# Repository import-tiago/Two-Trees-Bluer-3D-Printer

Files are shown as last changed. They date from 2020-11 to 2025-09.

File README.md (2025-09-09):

# Two Trees BlueR - 3D Printer

Documentation, firmware and set of utilities for my own use and personal needs.

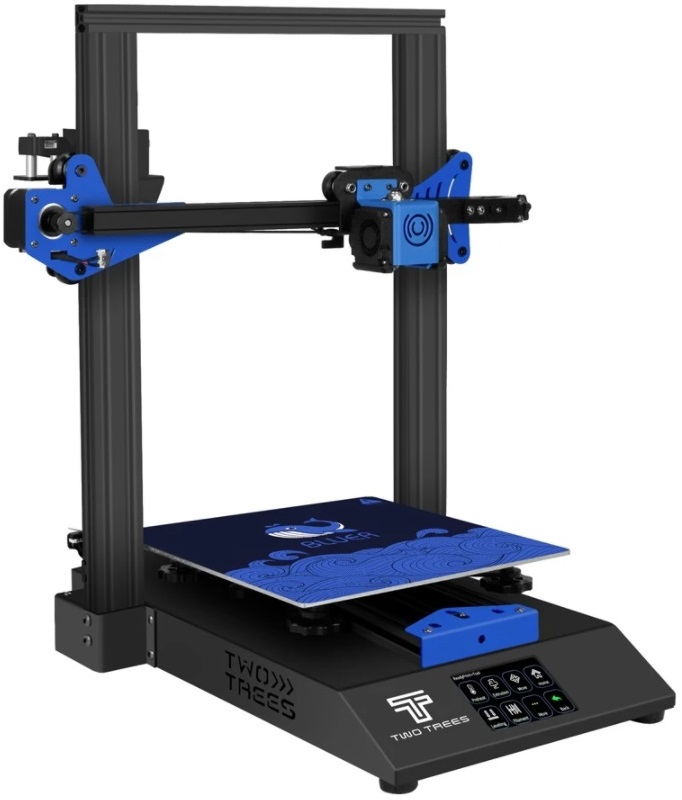
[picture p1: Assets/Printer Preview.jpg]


## Machine Specs
| Parameter | Value |
|--|--|
Number of nozzles|1|
Construction volume|235mm * 235mm * 280mm|
Printing method|SD-Card / online printing (by Serial UART communication through printer USB connector and some internet interface)|
IHM|3.5 inch color touch screen|
Machine speed|10~300mm/s|
Print speed|20~200mm/s|
Extrusion head temperature (highest)|260 °C|
Maximum hot bed temperature (highest)|100 °C|
Printing platform|Warm bed|
XY axis positioning accuracy|0.01mm|
Z axis positioning accuracy|0.004mm|
Recommended printed material|PLA, ABS and PETG|
Consumable filament diameter|1.75mm|
Print file format|G-Code|
Machine size|L=410mm * W=400mm * H=520mm|
Machine weight|7.5kg|
Power supply|127V~220V/240W|
Microcontroller|[STM32F103VET6 datasheet](Hardware/Motherboard/2.%20Datasheets/MCU/STM32F103VET6.pdf)|
Motor Driver|[TMC2209 datasheet](Hardware/Motherboard/2.%20Datasheets/Stepper%20Motor%20Driver/TMC2209.pdf)|
Stepper Motor|[US-17HS4401S datasheet](Hardware/Stepper%20Motors/US-17HS4401S.pdf)|
Motherboard|[MKS Robin Nano v1.2 schematic](Hardware/Motherboard/1.%20Schematic/MKS%20Robin%20Nano%20v1.2.pdf) ([source HW + FW](https://github.com/import-tiago-mks/MKS-Robin-Nano-V1.X))|
Display|[MKS TFT35](https://github.com/import-tiago-mks/MKS-TFT) - Parallel line communication interface (FSMC) (schematic not available)|

More information on the manufacturer's official website: https://twotrees3d.com/

# Firmware

Version|[Marlin 3D Printer Firmware](https://github.com/MarlinFirmware/Marlin/releases/tag/2.1.3-b3) (from release 2.1.3-b3) + [BlueR v3 Marlin Configurations](https://github.com/MarlinFirmware/Configurations/tree/release-2.1.3-b3/config/examples/Two%20Trees/BlueR/BlueR%20V3) (from release 2.1.3-b3) + Personal Customization|
--- | ---
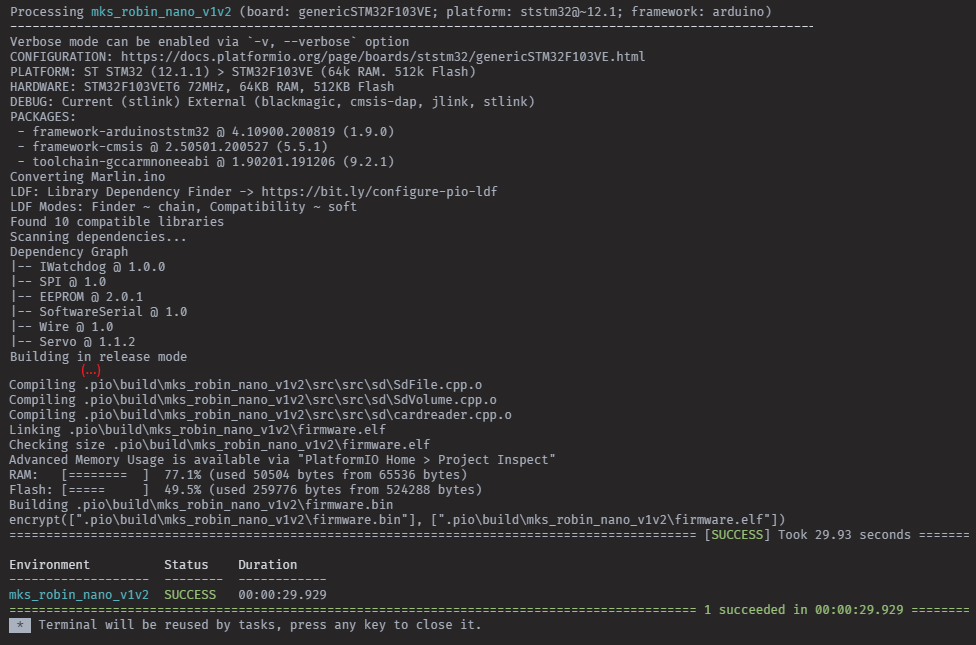
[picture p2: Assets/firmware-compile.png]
 

## Custom Modifications

**In `Configuration.h`:**
```cpp
#define BLUER_TMC2209
#define BLUER_BLTOUCH
#define Z_DRIVER_TYPE BASE_DRIVER_TYPE
#define E0_DRIVER_TYPE BASE_DRIVER_TYPE
#define Z_MIN_ENDSTOP_HIT_STATE HIGH
#define USE_PROBE_FOR_Z_HOMING
#define DEFAULT_AXIS_STEPS_PER_UNIT {160, 160, 800, 830}
#define NOZZLE_TO_PROBE_OFFSET { 0, -37, 0 }  // These values apply to *my* BLTouch mount. Adjust according to your specific bracket/mount.
//#define RESTORE_LEVELING_AFTER_G28
#define ENABLE_LEVELING_AFTER_G28
#define PREHEAT_BEFORE_LEVELING
#define ENDSTOP_NOISE_THRESHOLD 2
#define PROBING_FANS_OFF 
#define PROBING_ESTEPPERS_OFF 
#define PROBING_STEPPERS_OFF
#define DELAY_BEFORE_PROBING 200
#define MULTIPLE_PROBING 2
#define EXTRA_PROBING 1
#define GRID_MAX_POINTS_X 4
#define EXTRAPOLATE_BEYOND_GRID
#define Z_MIN_PROBE_REPEATABILITY_TEST
#define Y_MIN_POS 0
```

**In `Configuration_adv.h`:**
```cpp
#define BLTOUCH_DELAY 500
//#define BLTOUCH_FORCE_SW_MODE // must remain commented (issue #27235)
```

## Frequently Asked Questions

### What is my micro-stepping configuration?


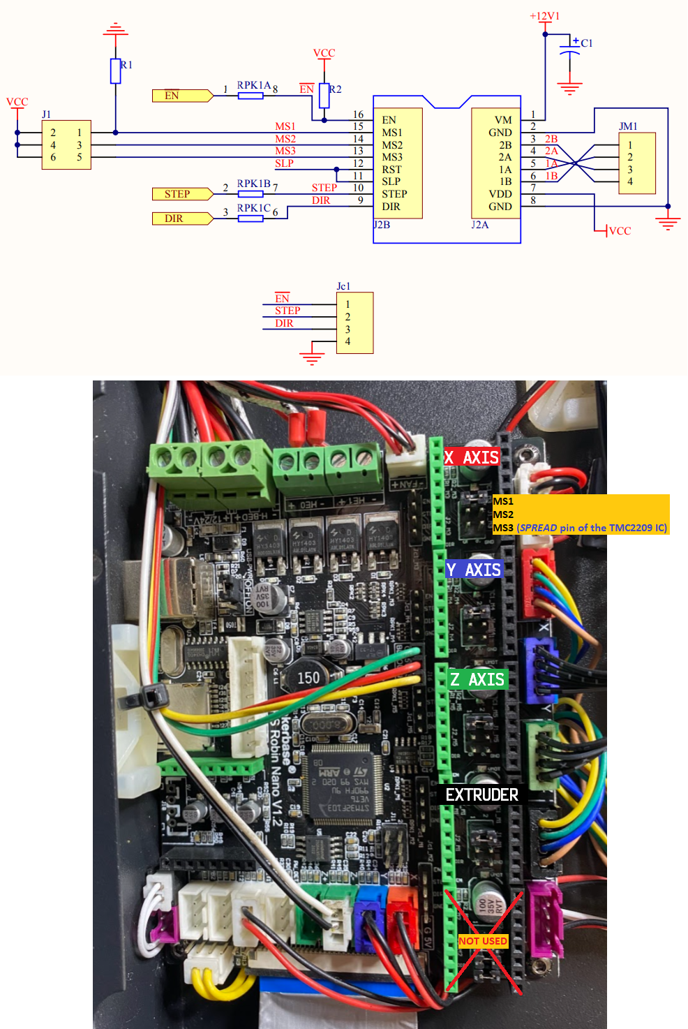
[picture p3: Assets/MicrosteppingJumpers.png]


### What VREF value I seted at motor-drivers (aka motors current definition)?

- X-axis VREF = 0.75V ∴ IRMS = 0.53A </br>
- Y-axis VREF = 0.85V ∴ IRMS = 0.60A </br>
- Z-axis VREF = 0.85V ∴ IRMS = 0.60A </br>
- E-axis VREF = 0.75V ∴ IRMS = 0.53A </br>

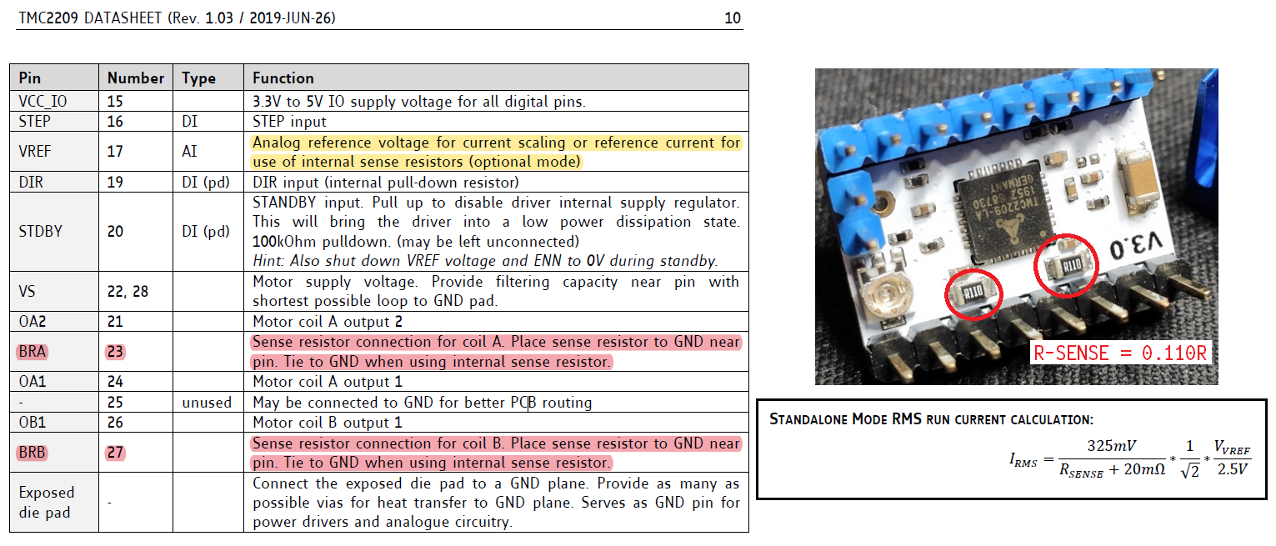
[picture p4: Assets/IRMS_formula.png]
<p align="center">    
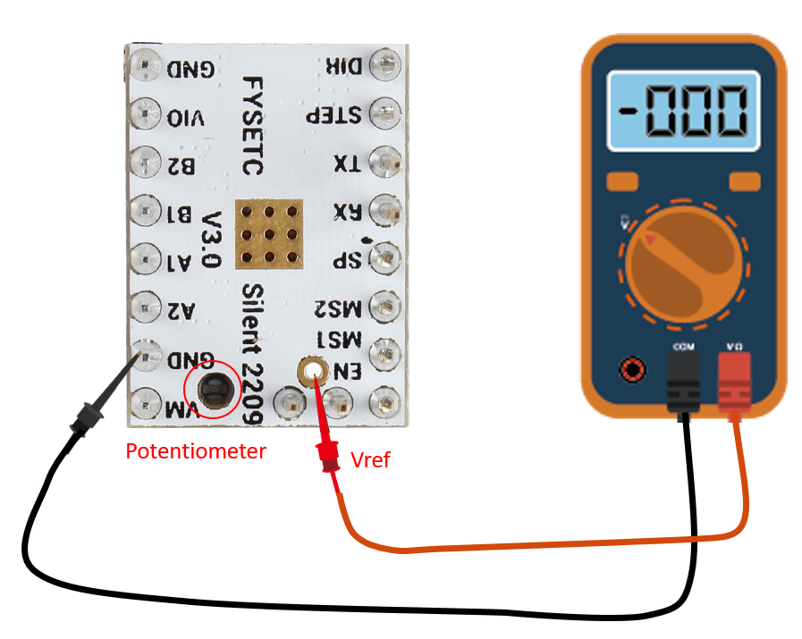
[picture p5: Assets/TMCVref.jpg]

  
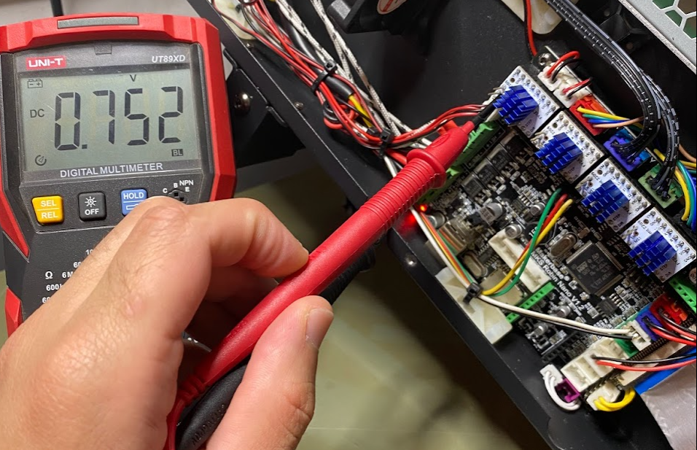
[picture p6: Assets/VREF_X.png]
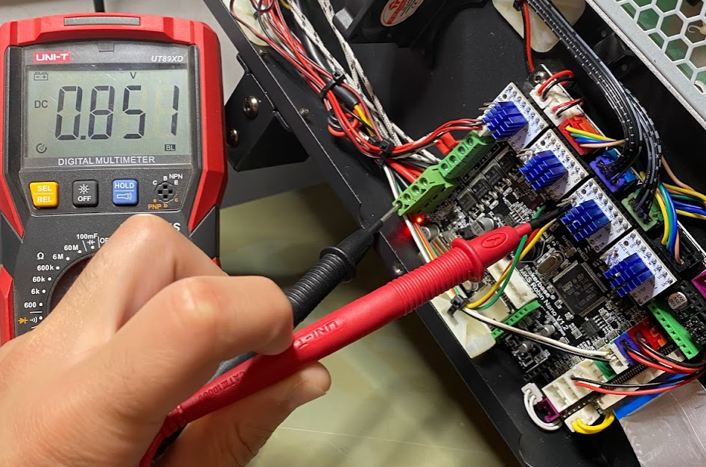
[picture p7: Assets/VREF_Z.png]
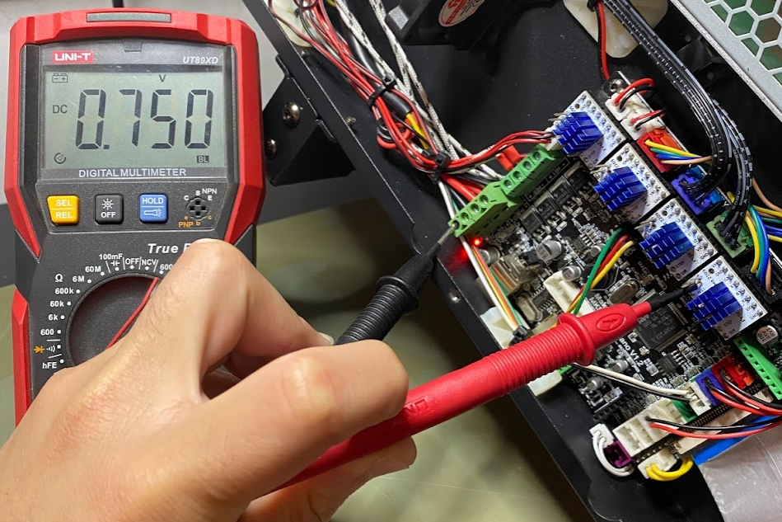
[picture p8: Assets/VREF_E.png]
|  |  |  |  |
|--|--|--|--|

## Print Samples

### Decoration Models
#### Among Us ([STL](https://www.thingiverse.com/thing:4626168))

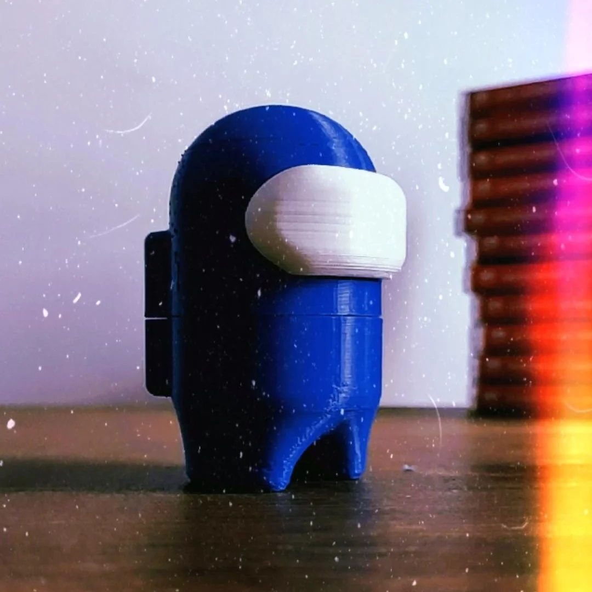
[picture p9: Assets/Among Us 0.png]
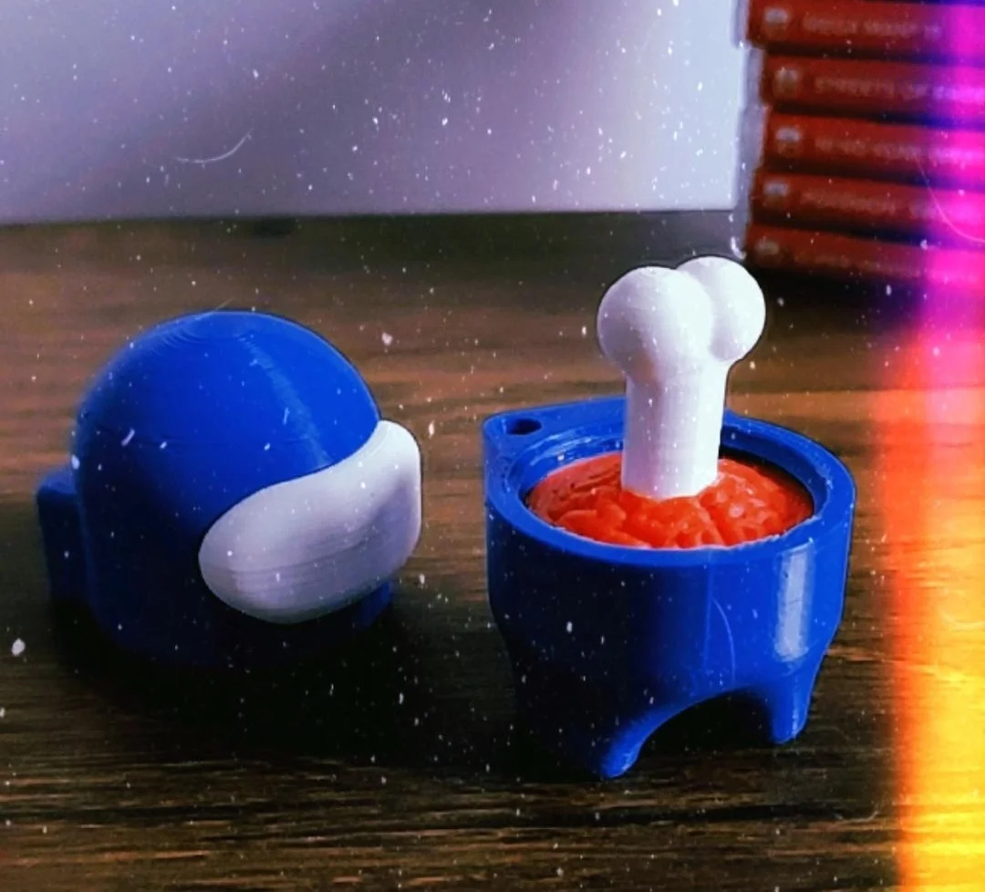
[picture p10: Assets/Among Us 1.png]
 | 
--- | ---

#### Bulbasaur Planter ([STL](https://www.thingiverse.com/thing:633081))


### Tools & Utensils
#### SD & Micro SD Card Box ([STL](https://www.thingiverse.com/thing:3611322))


#### 18650 Battery Box (x8) ([STL](https://www.thingiverse.com/thing:3191180))


#### Dust Filament Filter ([STL](https://www.thingiverse.com/thing:1692395))
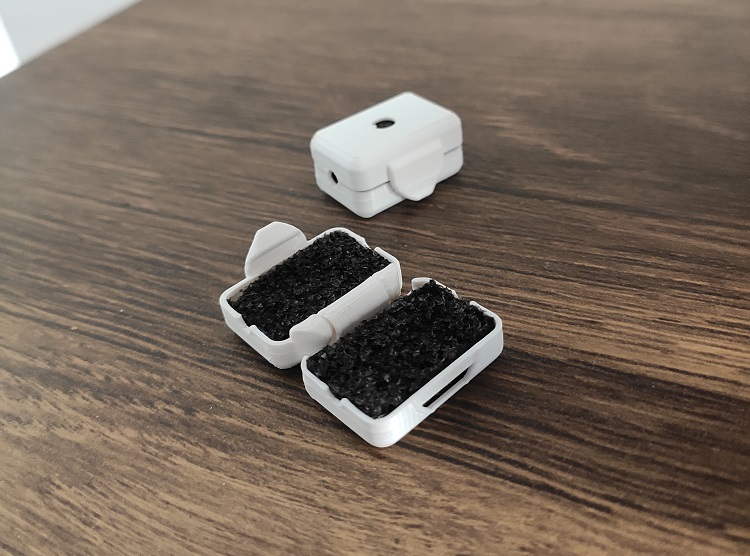
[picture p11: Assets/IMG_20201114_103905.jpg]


#### Universal Filament Clip ([STL](https://www.thingiverse.com/thing:3757356))


### Calibration & Tests
#### XYZ Cube ([STL](https://www.thingiverse.com/thing:1278865))
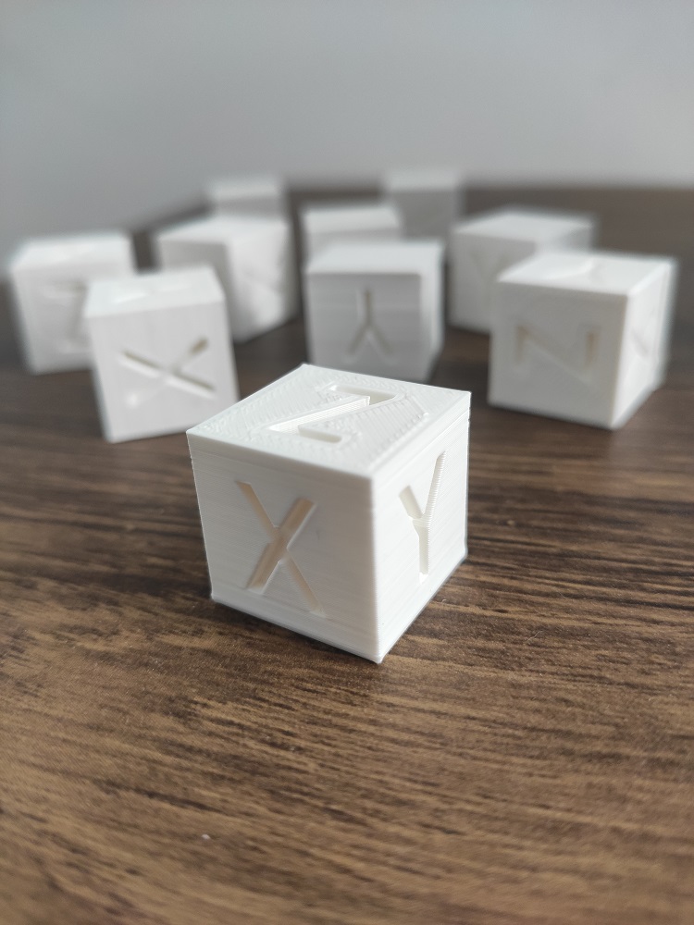
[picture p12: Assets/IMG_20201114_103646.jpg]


### BlueR Self-Upgrades Parts
#### BLTtouch Support (front mounting) ([STL](https://moltech3d.com/blog/2020/10/05/suporte-para-fixacao-do-bltouch-na-impressora-twotrees-bluer/))


## Improved Components and Upgrades
- [x] Stepper motor driver - [TMC2209](https://pt.aliexpress.com/item/1005004894012542.html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) at X, Y, Z and E - **ultra-silent controllers**
- [x] Auto leveling sensor - [3D Touch](https://pt.aliexpress.com/item/1005004256711867.html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) - **Automatic and improved bed leveling**
- [x] PEI spring steel sheet with magnetic base [235mm x 235mm](https://www.aliexpress.com/item/1005004111663711.html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) - **better adhesion and increase surface hardness**
- [x] Anti-backlash spring loaded nut - [T8](https://pt.aliexpress.com/item/32820989850.html?spm=a2g0o.cart.0.0.4d623c00aKJcGs&mp=1) - **Smooths lines on the z axis**

## Printer Details
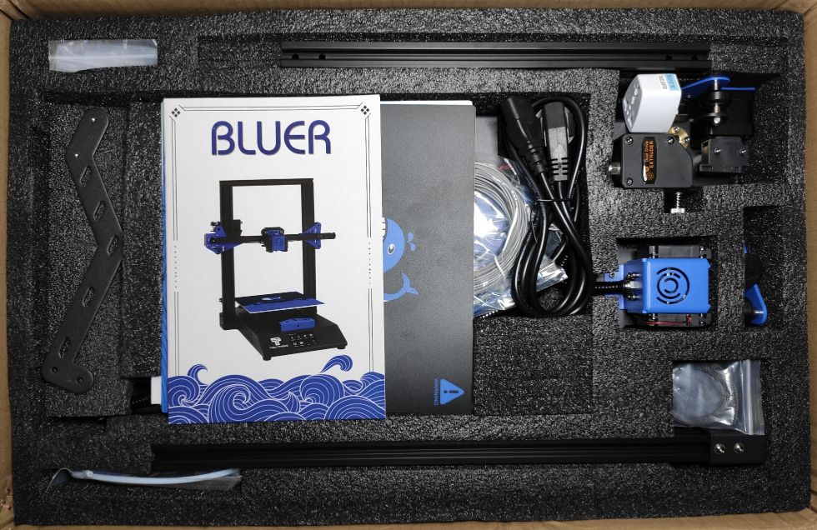
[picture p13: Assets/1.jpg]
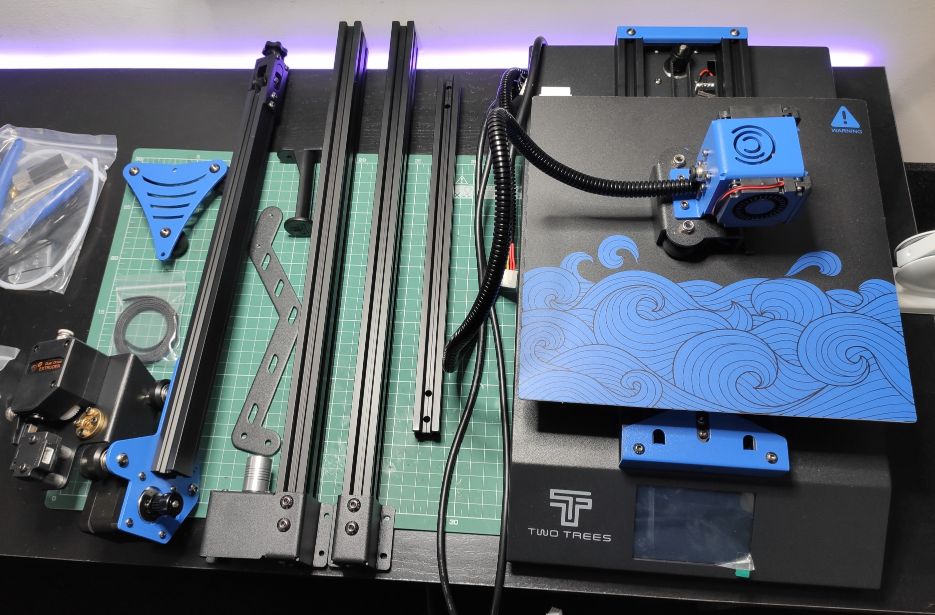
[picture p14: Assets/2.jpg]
|  |  |  |
|--|--|--|
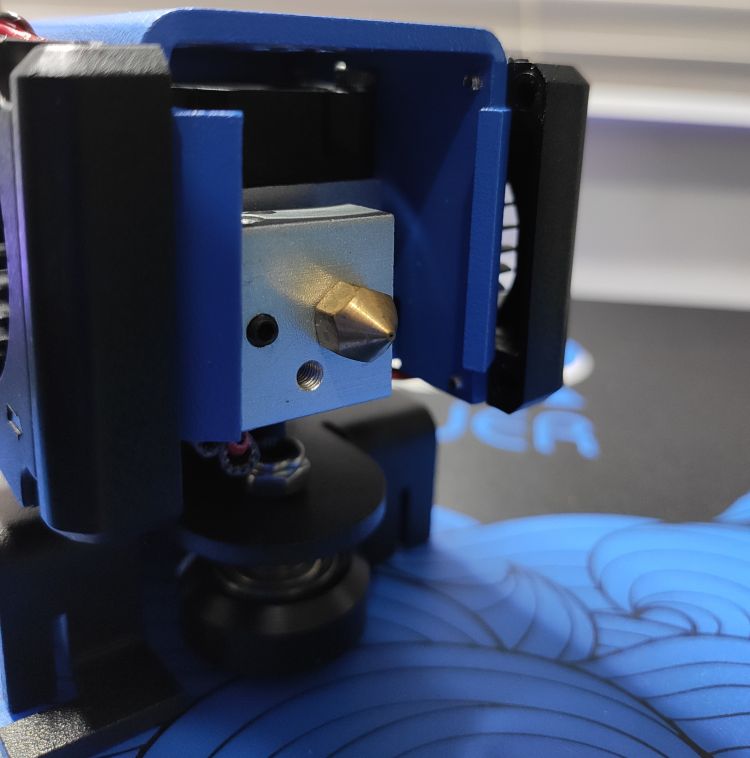
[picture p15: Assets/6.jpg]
|  |  |  |
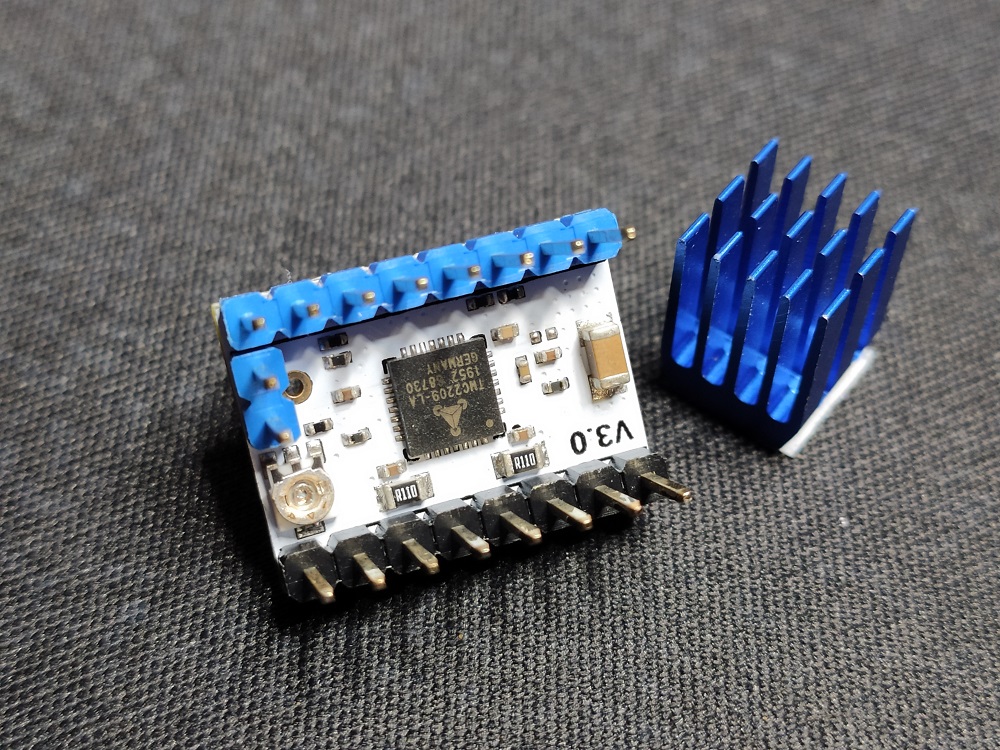
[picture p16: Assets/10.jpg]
|  |  |  |

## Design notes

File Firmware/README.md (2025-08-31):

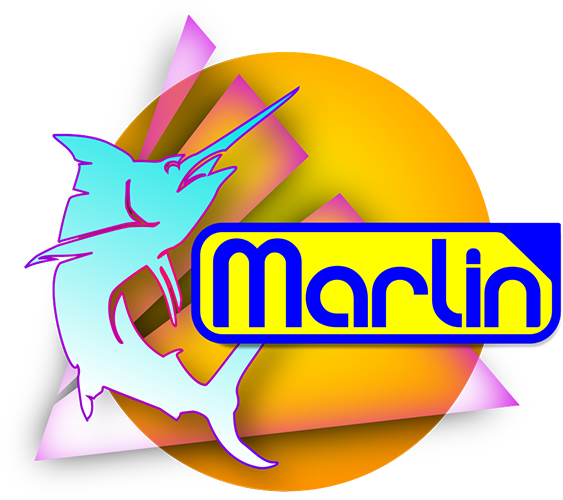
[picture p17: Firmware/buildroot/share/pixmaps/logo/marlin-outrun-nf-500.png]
MarlinFirmware's logo


<h1 align="center">Marlin 3D Printer Firmware</h1>

<p align="center">
    
    
    
    
    
    <br />
    
    
</p>

### 🌍 Translations
<table>
<tr>
  <td><a href="//translate.google.com/translate?u=github.com/MarlinFirmware/Marlin&sl=auto&tl=an">Aragonés</a></td>
  <td><a href="//translate.google.com/translate?u=github.com/MarlinFirmware/Marlin&sl=auto&tl=bg">Български</a></td>
  <td><a href="//translate.google.com/translate?u=github.com/MarlinFirmware/Marlin&sl=auto&tl=ca">Català</a></td>
  <td><a href="//translate.google.com/translate?u=github.com/MarlinFirmware/Marlin&sl=auto&tl=cs">Čeština</a></td>
  <td><a href="//translate.google.com/translate?u=github.com/MarlinFirmware/Marlin&sl=auto&tl=da">Dansk</a></td>
  <td><a href="//translate.google.com/translate?u=github.com/MarlinFirmware/Marlin&sl=auto&tl=de">Deutsch</a></td>
  <td><a href="//translate.google.com/translate?u=github.com/MarlinFirmware/Marlin&sl=auto&tl=el">Ελληνικά</a></td>
</tr>
<tr>
  <td><a href="//github.com/MarlinFirmware/Marlin">English</a></td>
  <td><a href="//translate.google.com/translate?u=github.com/MarlinFirmware/Marlin&sl=auto&tl=es">Español</a></td>
  <td><a href="//translate.google.com/translate?u=github.com/MarlinFirmware/Marlin&sl=auto&tl=eu">Euskara</a></td>
  <td><a href="//translate.google.com/translate?u=github.com/MarlinFirmware/Marlin&sl=auto&tl=fi">Suomi</a></td>
  <td><a href="//translate.google.com/translate?u=github.com/MarlinFirmware/Marlin&sl=auto&tl=fr">Français</a></td>
  <td><a href="//translate.google.com/translate?u=github.com/MarlinFirmware/Marlin&sl=auto&tl=gl">Galego</a></td>
  <td><a href="//translate.google.com/translate?u=github.com/MarlinFirmware/Marlin&sl=auto&tl=hr">Hrvatski</a></td>
</tr>
<tr>
  <td><a href="//translate.google.com/translate?u=github.com/MarlinFirmware/Marlin&sl=auto&tl=hu">Magyar</a></td>
  <td><a href="//translate.google.com/translate?u=github.com/MarlinFirmware/Marlin&sl=auto&tl=it">Italiano</a></td>
  <td><a href="//translate.google.com/translate?u=github.com/MarlinFirmware/Marlin&sl=auto&tl=ja">にほんご</a></td>
  <td><a href="//translate.google.com/translate?u=github.com/MarlinFirmware/Marlin&sl=auto&tl=ko">한국어</a></td>
  <td><a href="//translate.google.com/translate?u=github.com/MarlinFirmware/Marlin&sl=auto&tl=nl">Nederlands</a></td>
  <td><a href="//translate.google.com/translate?u=github.com/MarlinFirmware/Marlin&sl=auto&tl=pl">Polski</a></td>
  <td><a href="//translate.google.com/translate?u=github.com/MarlinFirmware/Marlin&sl=auto&tl=pt">Português</a></td>
</tr>
<tr>
  <td><a href="//translate.google.com/translate?u=github.com/MarlinFirmware/Marlin&sl=auto&tl=pt-BR">Português (Brasil)</a></td>
  <td><a href="//translate.google.com/translate?u=github.com/MarlinFirmware/Marlin&sl=auto&tl=ro">Română</a></td>
  <td><a href="//translate.google.com/translate?u=github.com/MarlinFirmware/Marlin&sl=auto&tl=ru">Русский</a></td>
  <td><a href="//translate.google.com/translate?u=github.com/MarlinFirmware/Marlin&sl=auto&tl=sk">Slovenčina</a></td>
  <td><a href="//translate.google.com/translate?u=github.com/MarlinFirmware/Marlin&sl=auto&tl=sv">Svenska</a></td>
  <td><a href="//translate.google.com/translate?u=github.com/MarlinFirmware/Marlin&sl=auto&tl=tr">Türkçe</a></td>
  <td><a href="//translate.google.com/translate?u=github.com/MarlinFirmware/Marlin&sl=auto&tl=uk">Українська</a></td>
</tr>
<tr>
  <td><a href="//translate.google.com/translate?u=github.com/MarlinFirmware/Marlin&sl=auto&tl=vi">Tiếng Việt</a></td>
  <td><a href="//translate.google.com/translate?u=github.com/MarlinFirmware/Marlin&sl=auto&tl=zh-CN">简体中文</a></td>
  <td><a href="//translate.google.com/translate?u=github.com/MarlinFirmware/Marlin&sl=auto&tl=zh-TW">繁體中文</a></td>
  <td></td>
  <td></td>
  <td></td>
  <td></td>
</tr>
</table>

Additional documentation can be found at the [Marlin Home Page](//marlinfw.org/).
Please test this firmware and let us know if it misbehaves in any way. Volunteers are standing by!

---

## Marlin 2.1.3 Beta 3

__Not for production use. Use with caution!__

This branch is for testing and bug fixes for Marlin 2.1.3. We'll use this time to collect bug reports and patch as many issues as we can. This should help the release version of 2.1.3 to be as robust as we can make it. Are you ready to do some testing?

## Configuration Migration

There are a lot of configuration changes in Marlin 2.1.3. We're working on automated tools to migrate configurations, so if you want to help us test those get in touch on the [Marlin Discord](//discord.com/servers/marlin-firmware-461605380783472640). If you need help migrating your configurations to Marlin 2.1.3, we'll have a dedicated channel for this purpose. Post your configurations there and we'll send back updated configurations. We can also send a built `firmware.bin` file if you need it.

## Example Configurations

Before you can build Marlin for your machine you'll need a configuration for your specific hardware. Upon request, your vendor will be happy to provide you with the complete source code and configurations for your machine, but you'll need to get updated configuration files if you want to install a newer version of Marlin. Fortunately, Marlin users have contributed dozens of tested configurations to get you started. Visit the [MarlinFirmware/Configurations](//github.com/MarlinFirmware/Configurations) repository to find the right configuration for your hardware.

## Marlin Builds

We now publish builds for all our posted example configurations. See the [MarlinBuilds](//github.com/MarlinFirmware/MarlinBuilds) repository for details. This is a new process so bear with us while we work out all the best variants. If you like the way an example configuration works but think it could be better, please submit your suggested improvements in a **Pull Request**.

## Building Marlin 2.1

To build and upload Marlin you will use one of these tools:

- The free [Visual Studio Code](//code.visualstudio.com/download) using the [Auto Build Marlin](//marlinfw.org/docs/basics/auto_build_marlin.html) extension.
- The free [Arduino IDE](//www.arduino.cc/en/main/software) : See [Building Marlin with Arduino](//marlinfw.org/docs/basics/install_arduino.html)
- You can also use VSCode with devcontainer : See [Installing Marlin (VSCode devcontainer)](http://marlinfw.org/docs/basics/install_devcontainer_vscode.html).

Marlin is optimized to build with the **PlatformIO IDE** extension for **Visual Studio Code**. You can still build Marlin with **Arduino IDE**, and we hope to improve the Arduino build experience, but at this time PlatformIO is the better choice.

## 8-Bit AVR Boards

We intend to continue supporting 8-bit AVR boards in perpetuity, maintaining a single codebase that can apply to all machines. We want casual hobbyists and tinkerers and owners of older machines to benefit from the community's innovations just as much as those with fancier machines. Plus, those old AVR-based machines are often the best for your testing and feedback!

## Hardware Abstraction Layer (HAL)

Marlin includes an abstraction layer to provide a common API for all the platforms it targets. This allows Marlin code to address the details of motion and user interface tasks at the lowest and highest levels with no system overhead, tying all events directly to the hardware clock.

Every new HAL opens up a world of hardware. At this time we need HALs for RP2040 and the Duet3D family of boards. A HAL that wraps an RTOS is an interesting concept that could be explored. Did you know that Marlin includes a Simulator that can run on Windows, macOS, and Linux? Join the Discord to help move these sub-projects forward!

### Supported Platforms

  Platform|MCU|Example Boards
  --------|---|-------
  [Arduino AVR](//www.arduino.cc/)|ATmega|RAMPS, Melzi, RAMBo
  [Teensy++ 2.0](//www.microchip.com/en-us/product/AT90USB1286)|AT90USB1286|Printrboard
  [Arduino Due](//www.arduino.cc/en/Guide/ArduinoDue)|SAM3X8E|RAMPS-FD, RADDS, RAMPS4DUE
  [ESP32](//github.com/espressif/arduino-esp32)|ESP32|FYSETC E4, E4d@BOX, MRR
  [GD32](//www.gigadevice.com/)|GD32 ARM Cortex-M4|Creality MFL GD32 V4.2.2
  [HC32](//www.huazhoucn.com/)|HC32|Ender-2 Pro, Voxelab Aquila
  [LPC1768](//www.nxp.com/products/processors-and-microcontrollers/arm-microcontrollers/general-purpose-mcus/lpc1700-cortex-m3/512-kb-flash-64-kb-sram-ethernet-usb-lqfp100-package:LPC1768FBD100)|ARM® Cortex-M3|MKS SBASE, Re-ARM, Selena Compact
  [LPC1769](//www.nxp.com/products/processors-and-microcontrollers/arm-microcontrollers/general-purpose-mcus/lpc1700-cortex-m3/512-kb-flash-64-kb-sram-ethernet-usb-lqfp100-package:LPC1769FBD100)|ARM® Cortex-M3|Smoothieboard, Azteeg X5 mini, TH3D EZBoard
  [Pico RP2040](//www.raspberrypi.com/documentation/microcontrollers/pico-series.html)|Dual Cortex M0+|BigTreeTech SKR Pico
  [STM32F103](//www.st.com/en/microcontrollers-microprocessors/stm32f103.html)|ARM® Cortex-M3|Malyan M200, GTM32 Pro, MKS Robin, BTT SKR Mini
  [STM32F401](//www.st.com/en/microcontrollers-microprocessors/stm32f401.html)|ARM® Cortex-M4|ARMED, Rumba32, SKR Pro, Lerdge, FYSETC S6, Artillery Ruby
  [STM32F7x6](//www.st.com/en/microcontrollers-microprocessors/stm32f7x6.html)|ARM® Cortex-M7|The Borg, RemRam V1
  [STM32G0B1RET6](//www.st.com/en/microcontrollers-microprocessors/stm32g0x1.html)|ARM® Cortex-M0+|BigTreeTech SKR mini E3 V3.0
  [STM32H743xIT6](//www.st.com/en/microcontrollers-microprocessors/stm32h743-753.html)|ARM® Cortex-M7|BigTreeTech SKR V3.0, SKR EZ V3.0, SKR SE BX V2.0/V3.0
  [SAMD21P20A](//www.adafruit.com/product/4064)|ARM® Cortex-M0+|Adafruit Grand Central M4
  [SAMD51P20A](//www.adafruit.com/product/4064)|ARM® Cortex-M4|Adafruit Grand Central M4
  [Teensy 3.2/3.1](//www.pjrc.com/teensy/teensy31.html)|MK20DX256VLH7 ARM® Cortex-M4|
  [Teensy 3.5](//www.pjrc.com/store/teensy35.html)|MK64FX512-VMD12 ARM® Cortex-M4|
  [Teensy 3.6](//www.pjrc.com/store/teensy36.html)|MK66FX1MB-VMD18 ARM® Cortex-M4|
  [Teensy 4.0](//www.pjrc.com/store/teensy40.html)|MIMXRT1062-DVL6B ARM® Cortex-M7|
  [Teensy 4.1](//www.pjrc.com/store/teensy41.html)|MIMXRT1062-DVJ6B ARM® Cortex-M7|
  Linux Native|x86 / ARM / RISC-V|Raspberry Pi GPIO
  Simulator|Windows, macOS, Linux|Desktop OS
  [All supported boards](//marlinfw.org/docs/hardware/boards.html#boards-list)|All platforms|All boards

## Marlin Support

The Issue Queue is reserved for Bug Reports and Feature Requests. Please use the following resources for help with configuration and troubleshooting:

- [Marlin Documentation](//marlinfw.org) - Official Marlin documentation
- [Marlin Discord](//discord.com/servers/marlin-firmware-461605380783472640) - Discuss issues with Marlin users and developers
- Facebook Group ["Marlin Firmware"](//www.facebook.com/groups/1049718498464482/)
- RepRap.org [Marlin Forum](//forums.reprap.org/list.php?415)
- Facebook Group ["Marlin Firmware for 3D Printers"](//www.facebook.com/groups/3Dtechtalk/)
- [Marlin Configuration](//www.youtube.com/results?search_query=marlin+configuration) on YouTube

## Contributing Patches

You can contribute patches by submitting a Pull Request to the ([bugfix-2.1.x](//github.com/MarlinFirmware/Marlin/tree/bugfix-2.1.x)) branch.

- We use branches named with a "bugfix" or "dev" prefix to fix bugs and integrate new features.
- Follow the [Coding Standards](//marlinfw.org/docs/development/coding_standards.html) to gain points with the maintainers.
- Please submit Feature Requests and Bug Reports to the [Issue Queue](//github.com/MarlinFirmware/Marlin/issues/new/choose). See above for user support.
- Whenever you add new features, be sure to add one or more build tests to `buildroot/tests`. Any tests added to a PR will be run within that PR on GitHub servers as soon as they are pushed. To minimize iteration be sure to run your new tests locally, if possible.
  - Local build tests:
    - All: `make tests-config-all-local`
    - Single: `make tests-config-single-local TEST_TARGET=...`
  - Local build tests in Docker:
    - All: `make tests-config-all-local-docker`
    - Single: `make tests-config-all-local-docker TEST_TARGET=...`
  - To run all unit test suites:
    - Using PIO: `platformio run -t test-marlin`
    - Using Make: `make unit-test-all-local`
    - Using Docker + make: `maker unit-test-all-local-docker`
  - To run a single unit test suite:
    - Using PIO: `platformio run -t marlin_<test-suite-name>`
    - Using make: `make unit-test-single-local TEST_TARGET=<test-suite-name>`
    - Using Docker + make: `maker unit-test-single-local-docker TEST_TARGET=<test-suite-name>`
- If your feature can be unit tested, add one or more unit tests. For more information see our documentation on [Unit Tests](test).

## Contributors

Marlin is constantly improving thanks to a huge number of contributors from all over the world bringing their specialties and talents. Huge thanks are due to [all the contributors](//github.com/MarlinFirmware/Marlin/graphs/contributors) who regularly patch up bugs, help direct traffic, and basically keep Marlin from falling apart. Marlin's continued existence would not be possible without them.

Marlin Firmware original logo design by Ahmet Cem TURAN [@ahmetcemturan](//github.com/ahmetcemturan).

## Project Leadership

Name|Role|Link|Donate
----|----|----|----
🇺🇸 Scott Lahteine|Project Lead|[[@thinkyhead](//github.com/thinkyhead)]|[💸 Donate](//marlinfw.org/docs/development/contributing.html#donate)
🇺🇸 Roxanne Neufeld|Admin|[[@Roxy-3D](//github.com/Roxy-3D)]|
🇺🇸 Keith Bennett|Admin|[[@thisiskeithb](//github.com/thisiskeithb)]|[💸 Donate](//github.com/sponsors/thisiskeithb)
🇺🇸 Jason Smith|Admin|[[@sjasonsmith](//github.com/sjasonsmith)]|
🇧🇷 Victor Oliveira|Admin|[[@rhapsodyv](//github.com/rhapsodyv)]|
🇬🇧 Chris Pepper|Admin|[[@p3p](//github.com/p3p)]|
🇳🇿 Peter Ellens|Admin|[[@ellensp](//github.com/ellensp)]|[💸 Donate](//ko-fi.com/ellensp)
🇺🇸 Bob Kuhn|Admin|[[@Bob-the-Kuhn](//github.com/Bob-the-Kuhn)]|
🇳🇱 Erik van der Zalm|Founder|[[@ErikZalm](//github.com/ErikZalm)]|

## Star History

<a id="starchart" href="//star-history.com/#MarlinFirmware/Marlin&Date">
  <picture>
    <source media="(prefers-color-scheme: dark)" srcset="https://api.star-history.com/svg?repos=MarlinFirmware/Marlin&type=Date&theme=dark" />
    <source media="(prefers-color-scheme: light)" srcset="https://api.star-history.com/svg?repos=MarlinFirmware/Marlin&type=Date" />
    Star History Chart
  </picture>
</a>

## License

Marlin is published under the [GPL license](/LICENSE) because we believe in open development. The GPL comes with both rights and obligations. Whether you use Marlin firmware as the driver for your open or closed-source product, you must keep Marlin open, and you must provide your compatible Marlin source code to end users upon request. The most straightforward way to comply with the Marlin license is to make a fork of Marlin on Github, perform your modifications, and direct users to your modified fork.

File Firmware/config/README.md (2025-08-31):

# Where have all the configurations gone?

Marlin configurations for specific machines are now maintained in their own repository at:

## https://github.com/MarlinFirmware/Configurations/tree/2.1.3-b3

Configuration files for use with the nightly `bugfix-2.1.x` branch can be downloaded from:

## https://github.com/MarlinFirmware/Configurations/archive/bugfix-2.1.x.zip

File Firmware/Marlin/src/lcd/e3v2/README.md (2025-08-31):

# DWIN for Creality Ender-3 v2

Marlin's Ender-3 v2 support requires the `DWIN_SET` included with the Ender-3 V2 [example configuration](https://github.com/MarlinFirmware/Configurations/tree/2.1.3-b3/config/examples/Creality/Ender-3%20V2).

## Easy Install

Copy the `DWIN_SET` folder onto a Micro-SD card and insert the card into the slot on the DWIN screen. Cycle the machine and wait for the screen to go from blue to orange. Turn the machine off and remove the SD card. When you turn on the machine the screen will display a "Creality" loading screen.

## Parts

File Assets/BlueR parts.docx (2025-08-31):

GENERIC HOTEND OVERVIEW

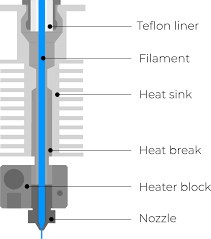
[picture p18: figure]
Anatomy of BCN 3D Sigma & Sigmax R19 extrusion system

NOZZLE TYPES

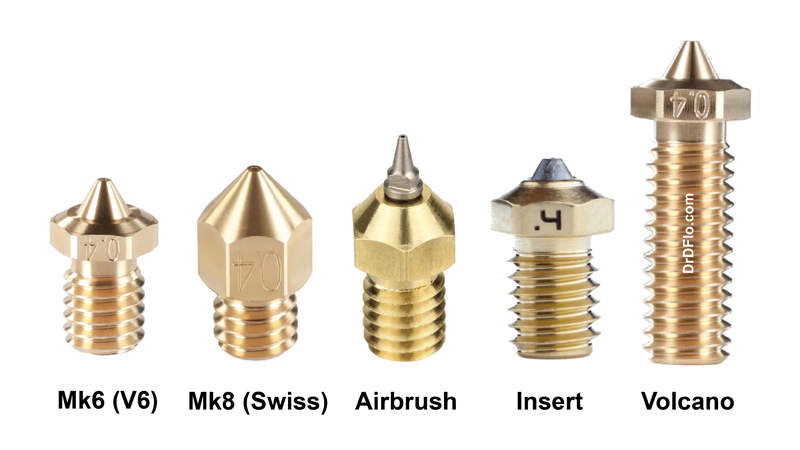
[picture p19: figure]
How to choose best nozzle for 3d printing?

HEATER BLOCK TYPES

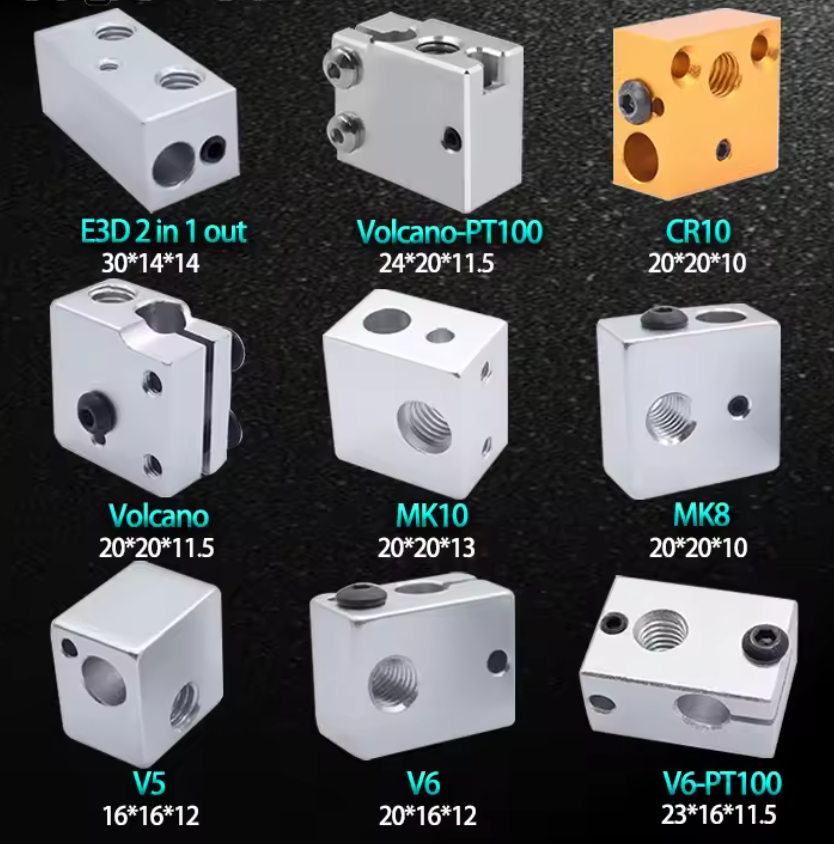
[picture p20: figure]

HEAT BREAK TYPES

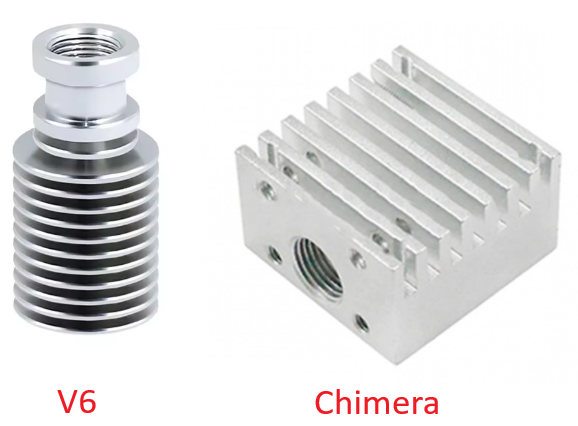
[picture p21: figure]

BLUER ORIGINAL PATS

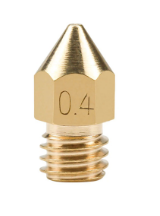
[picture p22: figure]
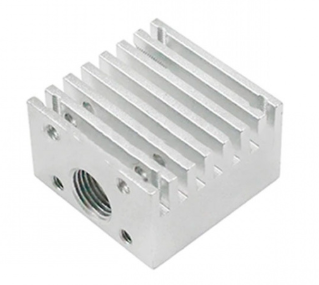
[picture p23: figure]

Nozzle: MK8 | Heat sink: Chimera (same as “Kraken” and “Cyclops”)

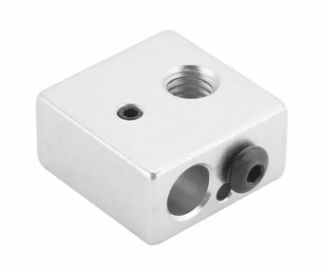
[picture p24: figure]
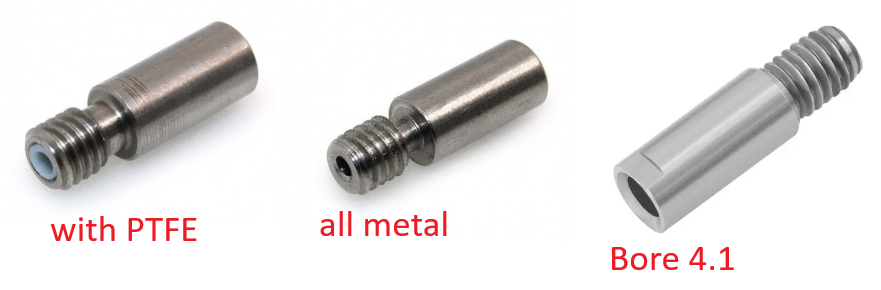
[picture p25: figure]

Heater block: MK8 | Heat Break: Chimera (same as “Kraken”)

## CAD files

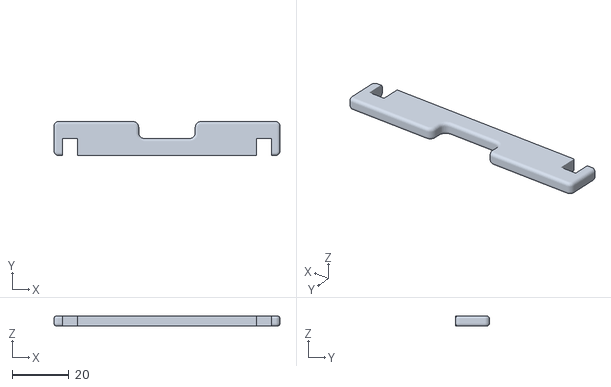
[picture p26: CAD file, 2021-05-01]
3D Models/Dupontt Jumper Wires Organizer/Short Spacers (10cm Jumpers).stl
80.0 x 12.0 x 3.70

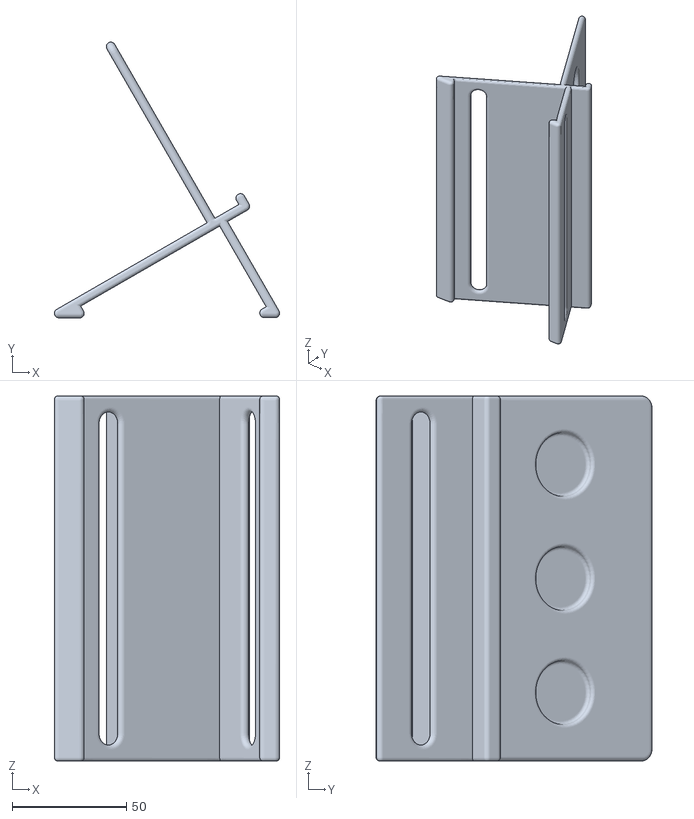
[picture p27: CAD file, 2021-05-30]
3D Models/Phone + Power Bank Table Stand/Table Phone Holder (Horizontal).stl
98.7 x 120.9 x 160.0

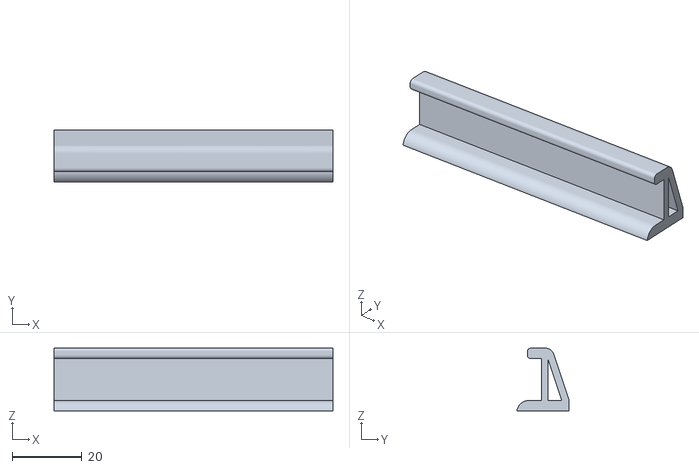
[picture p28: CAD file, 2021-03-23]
3D Models/Phone Wall Holder/Phone Wall Holder.stl
80.0 x 15.0 x 18.0

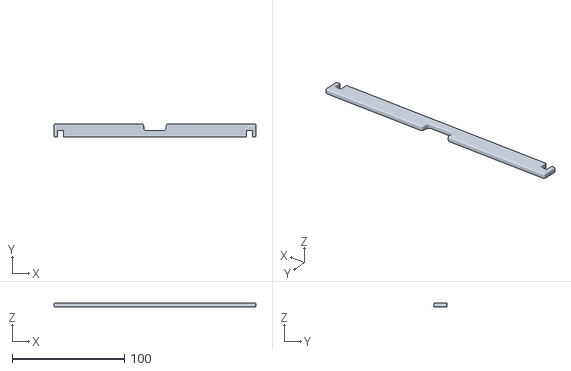
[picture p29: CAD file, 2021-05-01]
3D Models/Dupontt Jumper Wires Organizer/Long Spacers (20cm Jumpers).stl
180.0 x 12.0 x 3.70

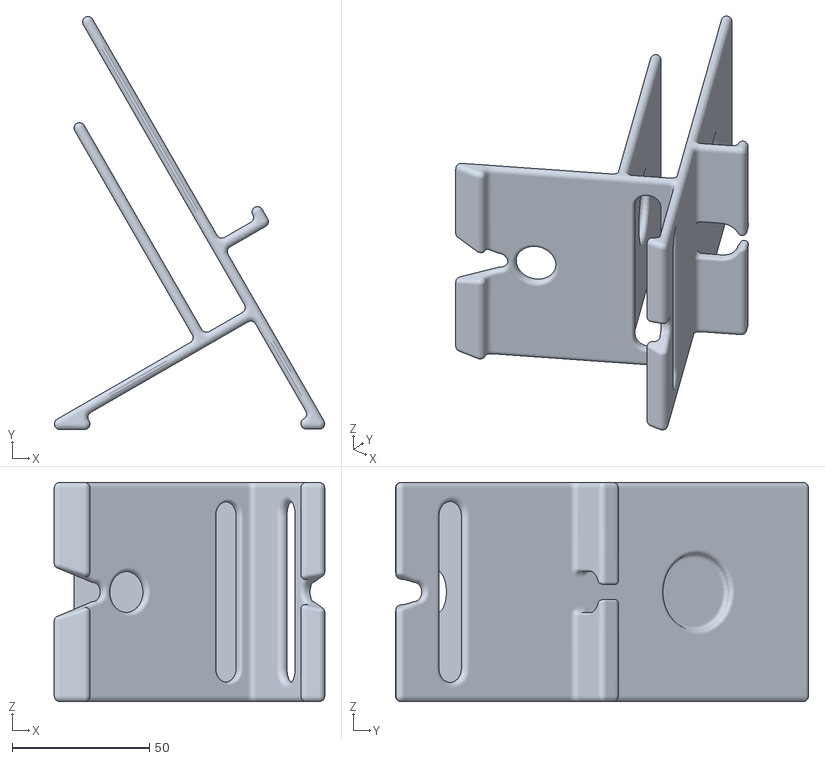
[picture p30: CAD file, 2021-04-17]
3D Models/Phone + Power Bank Table Stand/Phone + Power Bank (Flip Camera Version).stl
98.7 x 150.7 x 80.0

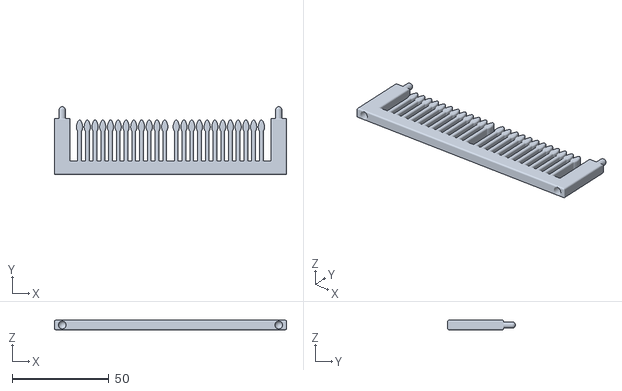
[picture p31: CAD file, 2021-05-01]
3D Models/Dupontt Jumper Wires Organizer/Sides Holders.stl
120.0 x 35.0 x 5.00

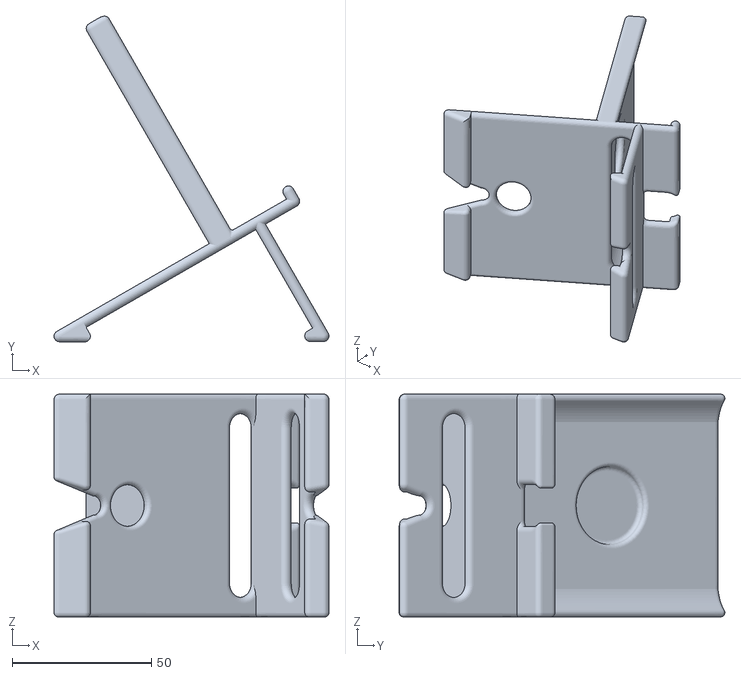
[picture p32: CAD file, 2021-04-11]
3D Models/Phone + Power Bank Table Stand/Phone + Power Bank (Induction Charging Version).stl
98.7 x 116.9 x 80.0

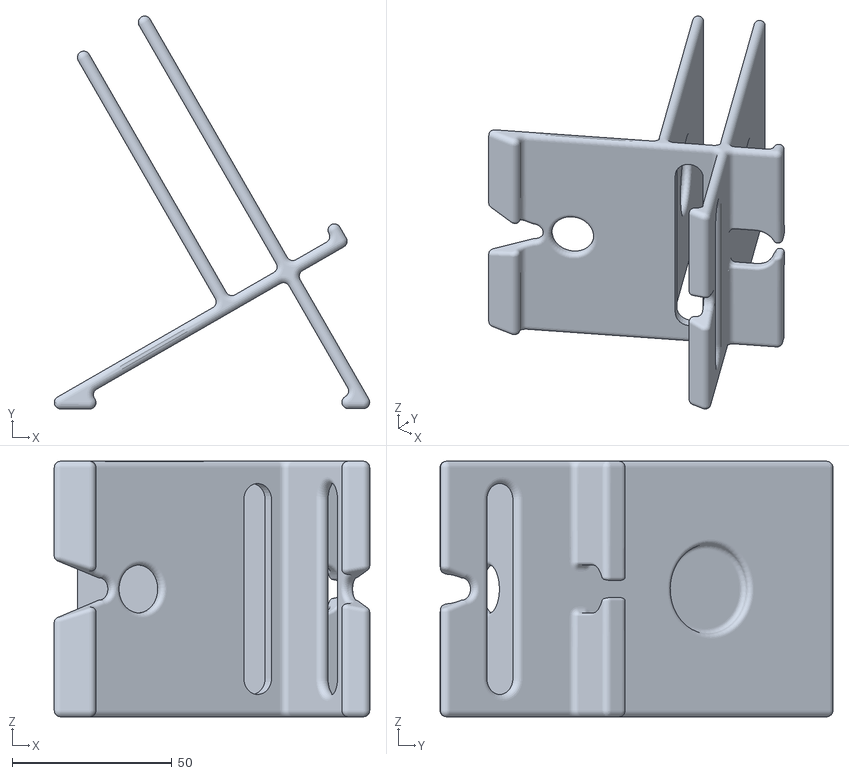
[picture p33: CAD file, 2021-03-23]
3D Models/Phone + Power Bank Table Stand/Phone + Power Bank Stand.stl
98.7 x 123.0 x 80.0

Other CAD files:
Hardware/Display/1. Schematic/MKS TS35 V2.0_001 SIZE.DWG

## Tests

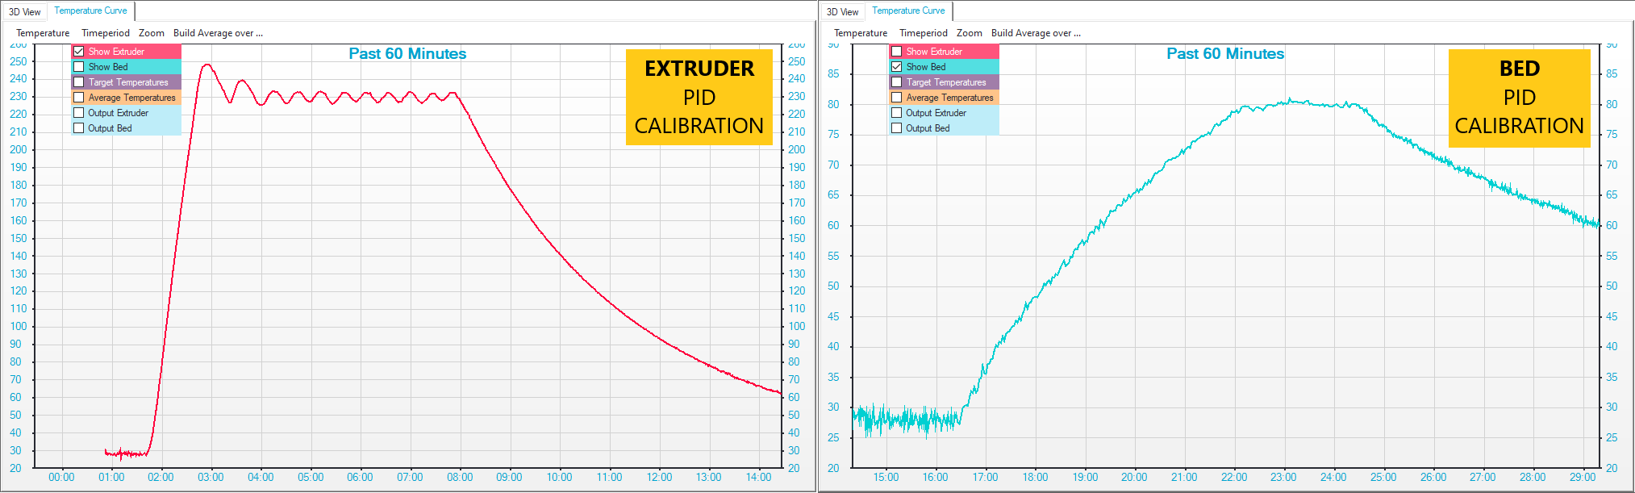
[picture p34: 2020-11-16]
Assets/PID Calibration.png

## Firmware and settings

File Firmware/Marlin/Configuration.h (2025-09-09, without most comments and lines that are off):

#pragma once
#define CONFIG_EXAMPLES_DIR "Two Trees/BlueR/BlueR V3"
#define BLUER_TMC2209 // Enable for the TMC2209 driver version
#define BLUER_BLTOUCH // Enable if you want to use BLTOUCH
#define CONFIGURATION_H_VERSION 02010300
#define STRING_CONFIG_H_AUTHOR \
    "(ils15, BlueR)" // Original author or contributor.
#define MOTHERBOARD BOARD_MKS_ROBIN_NANO
#define SERIAL_PORT 3
#define BAUDRATE 250000
#define SERIAL_PORT_2 1
#define CUSTOM_MACHINE_NAME "Two Trees BlueR"
#define BASE_DRIVER_TYPE TMC2209_STANDALONE
#define X_DRIVER_TYPE BASE_DRIVER_TYPE
#define Y_DRIVER_TYPE BASE_DRIVER_TYPE
#define Z_DRIVER_TYPE BASE_DRIVER_TYPE
#define E0_DRIVER_TYPE BASE_DRIVER_TYPE
#define EXTRUDERS 1
#define DEFAULT_NOMINAL_FILAMENT_DIA 1.75
#define TEMP_SENSOR_0 1
#define TEMP_SENSOR_1 0
#define TEMP_SENSOR_2 0
#define TEMP_SENSOR_3 0
#define TEMP_SENSOR_4 0
#define TEMP_SENSOR_5 0
#define TEMP_SENSOR_6 0
#define TEMP_SENSOR_7 0
#define TEMP_SENSOR_BED 1
#define TEMP_SENSOR_PROBE 0
#define TEMP_SENSOR_CHAMBER 0
#define TEMP_SENSOR_COOLER 0
#define TEMP_SENSOR_BOARD 0
#define TEMP_SENSOR_SOC 0
#define TEMP_SENSOR_REDUNDANT 0
#define DUMMY_THERMISTOR_998_VALUE 25
#define DUMMY_THERMISTOR_999_VALUE 100
#if TEMP_SENSOR_IS_MAX_TC(0)
#define MAX31865_SENSOR_OHMS_0 \
    100 // (Ω) Typically 100 or 1000 (PT100 or PT1000)
#define MAX31865_CALIBRATION_OHMS_0 \
    430 // (Ω) Typically 430 for Adafruit PT100; 4300 for Adafruit PT1000
#endif
#if TEMP_SENSOR_IS_MAX_TC(1)
#define MAX31865_SENSOR_OHMS_1 100
#define MAX31865_CALIBRATION_OHMS_1 430
#endif
#if TEMP_SENSOR_IS_MAX_TC(2)
#define MAX31865_SENSOR_OHMS_2 100
#define MAX31865_CALIBRATION_OHMS_2 430
#endif
#if TEMP_SENSOR_IS_MAX_TC(BED)
#define MAX31865_SENSOR_OHMS_BED 100
#define MAX31865_CALIBRATION_OHMS_BED 430
#endif
#if HAS_E_TEMP_SENSOR
#define TEMP_RESIDENCY_TIME \
    10 // (seconds) Time to wait for hotend to "settle" in M109
#define TEMP_WINDOW \
    1 // (°C) Temperature proximity for the "temperature reached" timer
#define TEMP_HYSTERESIS \
    3 // (°C) Temperature proximity considered "close enough" to the target
#endif
#if TEMP_SENSOR_BED
#define TEMP_BED_RESIDENCY_TIME \
    10 // (seconds) Time to wait for bed to "settle" in M190
#define TEMP_BED_WINDOW \
    1 // (°C) Temperature proximity for the "temperature reached" timer
#define TEMP_BED_HYSTERESIS \
    3 // (°C) Temperature proximity considered "close enough" to the target
#endif
#if TEMP_SENSOR_CHAMBER
#define TEMP_CHAMBER_RESIDENCY_TIME \
    10 // (seconds) Time to wait for chamber to "settle" in M191
#define TEMP_CHAMBER_WINDOW \
    1 // (°C) Temperature proximity for the "temperature reached" timer
#define TEMP_CHAMBER_HYSTERESIS \
    3 // (°C) Temperature proximity considered "close enough" to the target
#endif
#if TEMP_SENSOR_REDUNDANT
#define TEMP_SENSOR_REDUNDANT_SOURCE \
    E1 // The sensor that will provide the redundant reading.
#define TEMP_SENSOR_REDUNDANT_TARGET \
    E0 // The sensor that we are providing a redundant reading for.
#define TEMP_SENSOR_REDUNDANT_MAX_DIFF \
    10 // (°C) Temperature difference that will trigger a print abort.
#endif
#define HEATER_0_MINTEMP 5
#define HEATER_1_MINTEMP 5
#define HEATER_2_MINTEMP 5
#define HEATER_3_MINTEMP 5
#define HEATER_4_MINTEMP 5
#define HEATER_5_MINTEMP 5
#define HEATER_6_MINTEMP 5
#define HEATER_7_MINTEMP 5
#define BED_MINTEMP 5
#define CHAMBER_MINTEMP 5
#define HEATER_0_MAXTEMP 275
#define HEATER_1_MAXTEMP 275
#define HEATER_2_MAXTEMP 275
#define HEATER_3_MAXTEMP 275
#define HEATER_4_MAXTEMP 275
#define HEATER_5_MAXTEMP 275
#define HEATER_6_MAXTEMP 275
#define HEATER_7_MAXTEMP 275
#define BED_MAXTEMP 120
#define CHAMBER_MAXTEMP 60
#define HOTEND_OVERSHOOT 15 // (°C) Forbid temperatures over MAXTEMP - OVERSHOOT
#define BED_OVERSHOOT 10    // (°C) Forbid temperatures over MAXTEMP - OVERSHOOT
#define COOLER_OVERSHOOT 2  // (°C) Forbid temperatures closer than OVERSHOOT
#define PIDTEMP // See the PID Tuning Guide at
#define PID_MAX \
    255             // Limit hotend current while PID is active (see PID_FUNCTIONAL_RANGE
#define PID_K1 0.95 // Smoothing factor within any PID loop
#define DEFAULT_Kp 15.72
#define DEFAULT_Ki 1.24
#define DEFAULT_Kd 49.77
#define MAX_BED_POWER 255 // limits duty cycle to bed; 255=full current
#define PIDTEMPBED
#define DEFAULT_bedKp 66.39
#define DEFAULT_bedKi 12.94
#define DEFAULT_bedKd 227.14
#define MAX_CHAMBER_POWER \
    255 // limits duty cycle to chamber heater; 255=full current
#define PID_FUNCTIONAL_RANGE \
    20 // If the temperature difference between the target temperature and
#define PID_EDIT_MENU     // Add PID editing to the "Advanced Settings" menu.
#define PID_AUTOTUNE_MENU // Add PID auto-tuning to the "Advanced Settings"
#define PREVENT_COLD_EXTRUSION
#define EXTRUDE_MINTEMP 170
#define PREVENT_LENGTHY_EXTRUDE
#define EXTRUDE_MAXLENGTH 500
#define THERMAL_PROTECTION_HOTENDS // Enable thermal protection for all
#define THERMAL_PROTECTION_BED     // Enable thermal protection for the heated bed
#define THERMAL_PROTECTION_CHAMBER // Enable thermal protection for the heated
#define THERMAL_PROTECTION_COOLER  // Enable thermal protection for the laser
#define ENDSTOPPULLUPS
#define X_MIN_ENDSTOP_HIT_STATE LOW
#define X_MAX_ENDSTOP_HIT_STATE LOW
#define Y_MIN_ENDSTOP_HIT_STATE LOW
#define Y_MAX_ENDSTOP_HIT_STATE LOW
#define Z_MIN_ENDSTOP_HIT_STATE HIGH
#define Z_MAX_ENDSTOP_HIT_STATE LOW
#define I_MIN_ENDSTOP_HIT_STATE HIGH
#define I_MAX_ENDSTOP_HIT_STATE HIGH
#define J_MIN_ENDSTOP_HIT_STATE HIGH
#define J_MAX_ENDSTOP_HIT_STATE HIGH
#define K_MIN_ENDSTOP_HIT_STATE HIGH
#define K_MAX_ENDSTOP_HIT_STATE HIGH
#define U_MIN_ENDSTOP_HIT_STATE HIGH
#define U_MAX_ENDSTOP_HIT_STATE HIGH
#define V_MIN_ENDSTOP_HIT_STATE HIGH
#define V_MAX_ENDSTOP_HIT_STATE HIGH
#define W_MIN_ENDSTOP_HIT_STATE HIGH
#define W_MAX_ENDSTOP_HIT_STATE HIGH
#define Z_MIN_PROBE_ENDSTOP_HIT_STATE TERN(BLUER_BLTOUCH, HIGH, LOW)
#define ENDSTOP_NOISE_THRESHOLD 2
#define DEFAULT_AXIS_STEPS_PER_UNIT {160, 160, 800, 830}
#define EDITABLE_STEPS_PER_UNIT
#define DEFAULT_MAX_FEEDRATE {250, 250, 10, 50}
#define DEFAULT_MAX_ACCELERATION {3000, 3000, 100, 10000}
#define DEFAULT_ACCELERATION \
    750                                   // X, Y, Z and E acceleration for printing moves
#define DEFAULT_RETRACT_ACCELERATION 1000 // E acceleration for retracts
#define DEFAULT_TRAVEL_ACCELERATION \
    1000 // X, Y, Z acceleration for travel (non printing) moves
#define JUNCTION_DEVIATION_MM 0.3 // (mm) Distance from real junction edge
#define JD_HANDLE_SMALL_SEGMENTS  // Use curvature estimation instead of just
#define S_CURVE_ACCELERATION
#define Z_MIN_PROBE_USES_Z_MIN_ENDSTOP_PIN
#define USE_PROBE_FOR_Z_HOMING
#define BLTOUCH
#define NOZZLE_TO_PROBE_OFFSET {0, -37, 0}
#define PROBING_TOOL 0
#define PROBING_MARGIN 10
#define XY_PROBE_FEEDRATE (133 * 60) // (mm/min)
#define Z_PROBE_FEEDRATE_FAST (4 * 60) // (mm/min)
#define Z_PROBE_FEEDRATE_SLOW (Z_PROBE_FEEDRATE_FAST / 2) // (mm/min)
#define MULTIPLE_PROBING 2
#define EXTRA_PROBING 1
#define Z_CLEARANCE_DEPLOY_PROBE 10  // (mm) Z Clearance for Deploy/Stow
#define Z_CLEARANCE_BETWEEN_PROBES 5 // (mm) Z Clearance between probe points
#define Z_CLEARANCE_MULTI_PROBE 5    // (mm) Z Clearance between multiple probes
#define Z_PROBE_ERROR_TOLERANCE \
    3 // (mm) Tolerance for early trigger (<= -probe.offset.z + ZPET)
#define Z_PROBE_LOW_POINT \
    -2 // (mm) Farthest distance below the trigger-point to go before stopping
#define Z_MIN_PROBE_REPEATABILITY_TEST
#define PROBING_FANS_OFF         // Turn fans off when probing
#define PROBING_ESTEPPERS_OFF    // Turn all extruder steppers off when probing
#define PROBING_STEPPERS_OFF     // Turn all steppers off (unless needed to hold position) when probing (including extruders)
#define DELAY_BEFORE_PROBING 200 // (ms) To prevent vibrations from triggering piezo sensors
#define X_ENABLE_ON LOW
#define Y_ENABLE_ON LOW
#define Z_ENABLE_ON LOW
#define E_ENABLE_ON LOW // For all extruders
#define DISABLE_OTHER_EXTRUDERS // Keep only the active extruder enabled
#define INVERT_X_DIR false
#define INVERT_Y_DIR false
#define INVERT_Z_DIR false
#define INVERT_E0_DIR false
#define INVERT_E1_DIR false
#define INVERT_E2_DIR false
#define INVERT_E3_DIR false
#define INVERT_E4_DIR false
#define INVERT_E5_DIR false
#define INVERT_E6_DIR false
#define INVERT_E7_DIR false
#define Z_CLEARANCE_FOR_HOMING \
    10 // (mm) Minimal Z height before homing (G28) for Z clearance above the
#define X_HOME_DIR -1
#define Y_HOME_DIR -1
#define Z_HOME_DIR -1
#define X_BED_SIZE 235
#define Y_BED_SIZE 235
#define X_MIN_POS 0
#define Y_MIN_POS 0
#define Z_MIN_POS 0
#define X_MAX_POS X_BED_SIZE
#define Y_MAX_POS Y_BED_SIZE
#define Z_MAX_POS 280
#define MIN_SOFTWARE_ENDSTOPS
#define MIN_SOFTWARE_ENDSTOP_X
#define MIN_SOFTWARE_ENDSTOP_Y
#define MIN_SOFTWARE_ENDSTOP_Z
#define MIN_SOFTWARE_ENDSTOP_I
#define MIN_SOFTWARE_ENDSTOP_J
#define MIN_SOFTWARE_ENDSTOP_K
#define MIN_SOFTWARE_ENDSTOP_U
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

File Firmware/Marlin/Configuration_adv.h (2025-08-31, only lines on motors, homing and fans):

#define E0_AUTO_FAN_PIN FAN1_PIN
#define E1_AUTO_FAN_PIN -1
#define E2_AUTO_FAN_PIN -1
#define E3_AUTO_FAN_PIN -1
#define E4_AUTO_FAN_PIN -1
#define E5_AUTO_FAN_PIN -1
#define E6_AUTO_FAN_PIN -1
#define E7_AUTO_FAN_PIN -1
#define CHAMBER_AUTO_FAN_PIN -1
#define COOLER_AUTO_FAN_PIN -1
#define HOMING_BUMP_MM {5, 5, 2}      // (linear=mm, rotational=°) Backoff from endstops after first bump
#define HOMING_BUMP_DIVISOR {2, 2, 4} // Re-Bump Speed Divisor (Divides the Homing Feedrate)
#define QUICK_HOME // If G28 contains XY do a diagonal move first
#define MICROSTEP_MODES {16, 16, 16, 16, 16, 16} // [1,2,4,8,16]
#define ADVANCED_PAUSE_FEATURE
#define ADVANCED_PAUSE_PURGE_FEEDRATE 3 // (mm/s) Extrude feedrate (after loading). Should be slower than load feedrate.
#define ADVANCED_PAUSE_PURGE_LENGTH 50  // (mm) Length to extrude after loading.
#define ADVANCED_PAUSE_RESUME_PRIME 0   // (mm) Extra distance to prime nozzle after returning from park.

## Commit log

2020-11-02 Igor default + Z fix + E fix
    [Configuration.h, Configuration_adv.h]
2020-11-02 BL-Touch ENABLE (Bed-Leveling OFF)
    [Configuration.h]
2020-11-02 Auto Bed-Leveling ENABLE
    [Configuration.h]
2020-11-06 New 3D models added
    [Bulbasaur Planter.3mf, Bulbasaur Planter.stl, Lowest_poly_thinker.stl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]
2020-11-08 New directory structure
    [3DBenchy.3mf, 3DBenchy_-_Multi-part_-_Single_-_Bridge_roof_-_3DBenchy.com.stl, 3DBenchy_-_Multi-part_-_Single_-_Bridge_walls_-_3DBenchy.com.stl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]
2020-11-12 Get this files at moltech3d.com
    [BLTouch_Support.stl]
2020-11-12 New 3D model added
    [Bed_Levelling_Ender_3.stl]
2020-11-14 New directories structure
    [Bed Level.3mf, SmartTemperatureTower.stl, SmartTemperatureTower_ABS_200-250.stl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]
2020-11-14 New Cura project setup added
    [Temperature Tower PLA (200-250 °C).3mf]
2020-11-18 'CONFIGURATION_H_VERSION' and 'CONFIGURATION_ADV_H_VERSION' updated to 020008
    [Configuration.h, Configuration_adv.h]
2020-11-19 Display docs added
    [MKS TS35 V2.0_001 SIZE.DWG]
2020-11-19 Stepper motors docs added
2020-11-19 Marlin 3D Printer Firmware 2.0.x (Original)
    [Configuration.h, Configuration_adv.h]
2020-11-19 BlueR v3 Marlin Configurations (Original)
    [Configuration.h, Configuration_adv.h]
2020-11-20 TMC2209 + BLTouch activated
    [Configuration.h, Configuration_adv.h]
2020-11-20 STEP's Z-AXIS updated to 800 and E-AXIS to 830
    [Configuration.h]
2020-11-27 Merged with the last aproved pull requests and the #334 open one
    [Configuration.h, Configuration_adv.h]
2020-11-28 E0 DEFAULT_MAX_ACCELERATION from 10k to 1k
    [Configuration.h]
2021-03-22 Marlin and configuration files updated with the latest versions from branch 'bugfix-2.0.x' 'available on 3/21/2021'
    [Configuration.h, Configuration_adv.h]
2021-03-23 New files and firectories structure
    [02_Body.stl, 04_Bone.stl, 05_Visor.stl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]
2021-03-23 New STL file added
    [Phone + Power Bank Stand.stl, Phone Wall Holder.stl]
2021-03-27 Updated with the latest versions from branch 'bugfix-2.0.x' available on 3/26/2021
    [Configuration_adv.h]
2021-04-11 New model added
    [Phone + Power Bank (Induction Charging Version).stl]
2021-04-17 New phone holder version added
    [Phone + Power Bank (Flip CAM Version).stl]
2021-04-17 New images added
    [Phone + Power Bank (Flip Camera Version).stl]
2021-05-01 Firmware updated to Marlin release 2.0.8
    [Configuration.h, Configuration_adv.h, Long Spacers (20cm Jumpers).stl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]
2021-05-23 Firmware updated to Marlin release 2.0.8.1
    [Configuration.h, Configuration_adv.h]
2021-05-30 Firmware updated to Marlin release 2.0.8.2
2021-07-09 Firmware updated to Marlin release 2.0.9.1
    [Configuration.h, Configuration_adv.h]
2021-10-05 Firmware updated to Marlin release 2.0.9.2
    [Configuration.h, Configuration_adv.h]
2021-10-12 Enabled 'Host Action Commands' in Marlin
    [Configuration_adv.h]
2021-12-31 Firmware updated to Marlin release 2.0.9.3
    [Configuration.h, Configuration_adv.h, esp32.csv]
2022-09-17 Firmware updated to Marlin release 2.1.1
    [Configuration.h, Configuration_adv.h]
2023-02-18 Marlin updated to release v2.1.2
    [Configuration.h, Configuration_adv.h]
2023-04-12 motor current definition details
2024-12-26 firmware updated to release v2.1.3-b1
    [Configuration.h, Configuration_adv.h]
2025-08-31 firmware updated to release v2.1.3-b3
    [Configuration.h, Configuration_adv.h]
2025-09-09 Change Y_MIN_POS from 5 to 0
    [Configuration.h]

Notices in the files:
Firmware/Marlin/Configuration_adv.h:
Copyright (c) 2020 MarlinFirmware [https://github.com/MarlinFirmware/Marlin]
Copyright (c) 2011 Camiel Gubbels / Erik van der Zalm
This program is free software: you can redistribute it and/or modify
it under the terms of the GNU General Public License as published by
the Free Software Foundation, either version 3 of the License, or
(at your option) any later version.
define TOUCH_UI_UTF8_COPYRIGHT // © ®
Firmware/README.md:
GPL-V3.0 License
